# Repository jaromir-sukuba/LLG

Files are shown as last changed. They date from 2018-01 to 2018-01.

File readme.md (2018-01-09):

This is repository for project LLG - ligh level geolocator.
This geolocator uses movement of sun, sensed by single photoresistor, to estimate its own location on earth with accuracy of few dozens of kilometers. It is able to display and log the position for decades - 10 years of running/logging with display on, 30 years of runtime with display off, though only 22 years of logging memeory. Considering the battery has shelf life ~ 10 years, it's not that bad. 



/fw/ - MPLABX project expecting XC16 compiler to build. 

/hw/pcb/ - Eagle design files. Created in Eagle 6.4, 5x5cm, so it fits free version.

/hw/enclosure/ - FreeCad and stl files of enclosure I used



See https://hackaday.io/project/28550-light-level-geolocator for more.

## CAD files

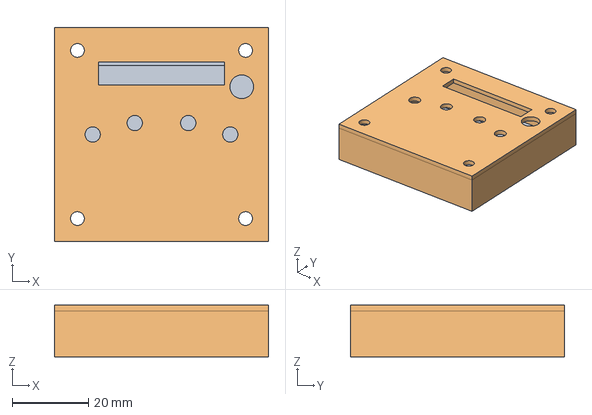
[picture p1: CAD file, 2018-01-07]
hw/enclosure/llg_enclosure.fcstd
56.0 x 56.0 x 13.5 mm

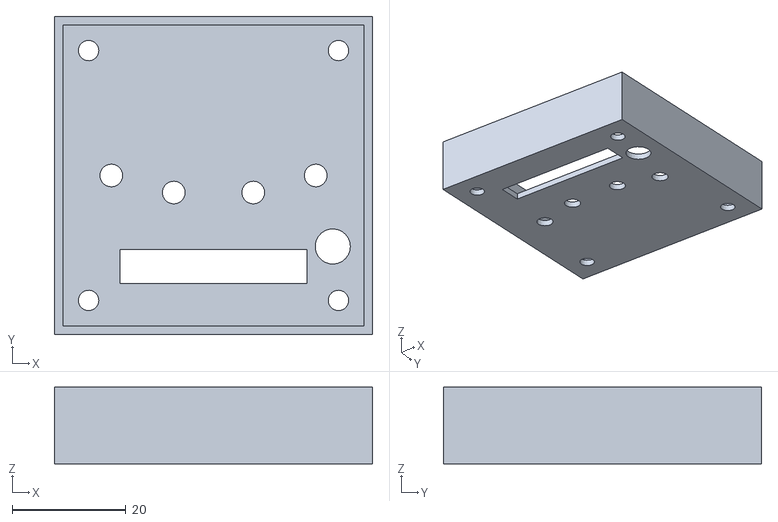
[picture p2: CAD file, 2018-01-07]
hw/enclosure/llg_part1.stl
56.0 x 56.0 x 13.5

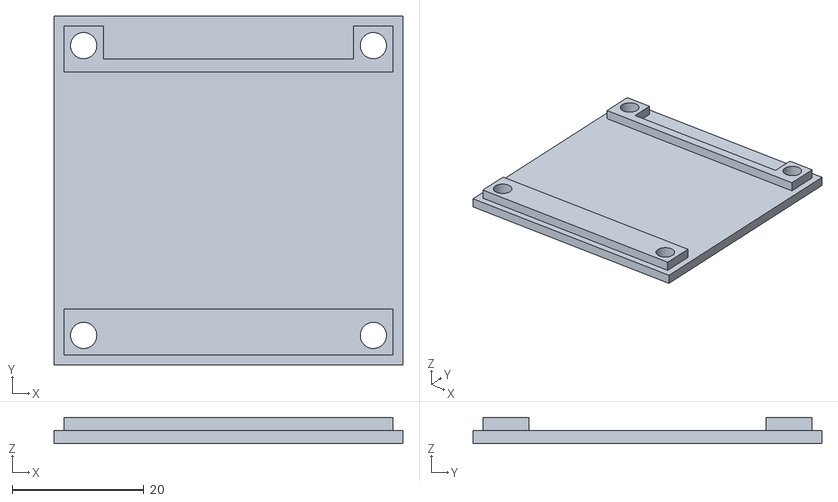
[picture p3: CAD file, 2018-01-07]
hw/enclosure/llg_part2.stl
53.0 x 53.0 x 4.00

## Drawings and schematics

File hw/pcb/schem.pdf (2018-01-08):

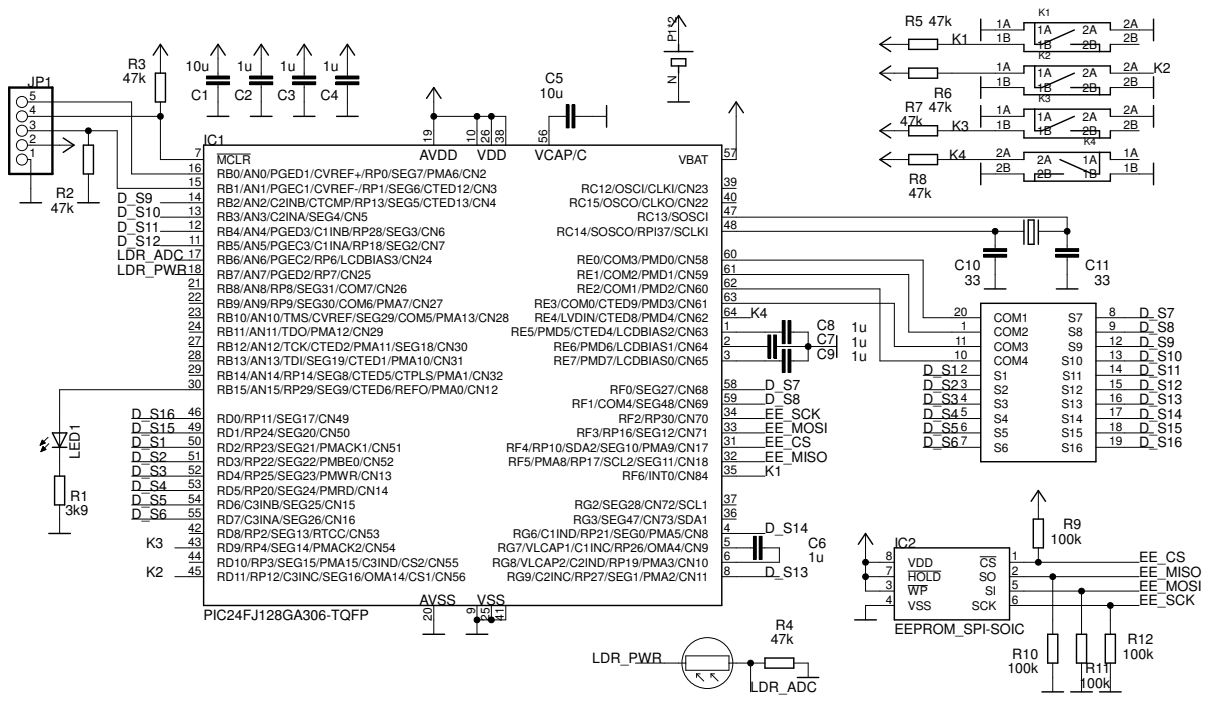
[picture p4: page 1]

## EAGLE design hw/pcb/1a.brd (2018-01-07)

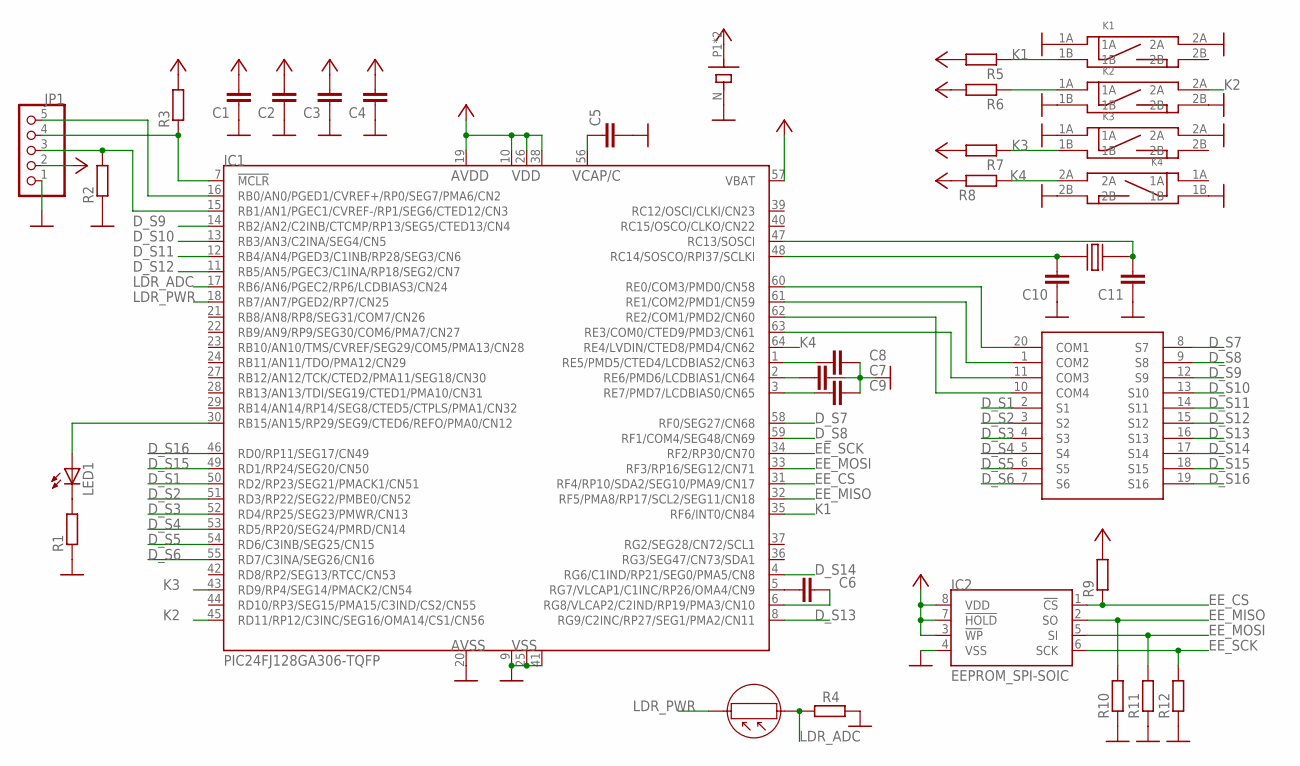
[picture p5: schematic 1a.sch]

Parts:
C1: C_1206; R1206
C2, C3, C4, C5, C6, C7, C8, C9, C10, C11: C_0603; 0603
IC1: PIC24FJ128GA306-TQFP; TQFP64-10X10
IC2: EEPROM_SPI-SOIC; SO-08
JP1: PINHD-1X05_2.00; 1X05M
K1, K2, K3, K4: SWITCH_BD_B; SW_SMD2
LCD1: LCD_DE188
LDR1: LDR; LDR_5
LED1: LEDCHIPLED_0805; CHIPLED_0805
R1, R2, R3, R4, R5, R6, R7, R8, R9, R10, R11, R12: R_0603; 0603
U$1: BATTK3002; BATT_KEYS3002
X1: CRYST_TC26MC146; CRYST_MC146

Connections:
D_S1: IC1.50 (RD2/RP23/SEG21/PMACK1/CN51), LCD1.2 (S1)
D_S2: IC1.51 (RD3/RP22/SEG22/PMBE0/CN52), LCD1.3 (S2)
D_S3: IC1.52 (RD4/RP25/SEG23/PMWR/CN13), LCD1.4 (S3)
D_S4: IC1.53 (RD5/RP20/SEG24/PMRD/CN14), LCD1.5 (S4)
D_S5: IC1.54 (RD6/C3INB/SEG25/CN15), LCD1.6 (S5)
D_S6: IC1.55 (RD7/C3INA/SEG26/CN16), LCD1.7 (S6)
D_S7: IC1.58 (RF0/SEG27/CN68), LCD1.8 (S7)
D_S8: IC1.59 (RF1/COM4/SEG48/CN69), LCD1.9 (S8)
D_S9: IC1.14 (RB2/AN2/C2INB/CTCMP/RP13/SEG5/CTED13/CN4), LCD1.12 (S9)
D_S10: IC1.13 (RB3/AN3/C2INA/SEG4/CN5), LCD1.13 (S10)
D_S11: IC1.12 (RB4/AN4/PGED3/C1INB/RP28/SEG3/CN6), LCD1.14 (S11)
D_S12: IC1.11 (RB5/AN5/PGEC3/C1INA/RP18/SEG2/CN7), LCD1.15 (S12)
D_S13: IC1.8 (RG9/C2INC/RP27/SEG1/PMA2/CN11), LCD1.16 (S13)
D_S14: IC1.4 (RG6/C1IND/RP21/SEG0/PMA5/CN8), LCD1.17 (S14)
D_S15: IC1.49 (RD1/RP24/SEG20/CN50), LCD1.18 (S15)
D_S16: IC1.46 (RD0/RP11/SEG17/CN49), LCD1.19 (S16)
EE_CS: IC1.31 (RF4/RP10/SDA2/SEG10/PMA9/CN17), IC2.1 (!CS), R9.1
EE_MISO: IC1.32 (RF5/PMA8/RP17/SCL2/SEG11/CN18), IC2.2 (SO), R10.2
EE_MOSI: IC1.33 (RF3/RP16/SEG12/CN71), IC2.5 (SI), R11.2
EE_SCK: IC1.34 (RF2/RP30/CN70), IC2.6 (SCK), R12.2
GND: C1.1, C2.1, C3.1, C4.1, C5.2, C7.1, C8.1, C9.1, C10.1, C11.1, IC1.9 (VSS), IC1.20 (AVSS), IC1.25 (VSS), IC1.41 (VSS), IC2.4 (VSS), JP1.1, K1.1A, K1.2A, K2.1B, K2.2B, K3.1A, K3.2A, K4.1B, K4.2B, R1.1, R2.1, R4.1, R10.1, R11.1, R12.1, U$1.N (M)
K1: IC1.35 (RF6/INT0/CN84), K1.1B, R5.1
K2: IC1.45 (RD11/RP12/C3INC/SEG16/OMA14/CS1/CN56), K2.2A
K3: IC1.43 (RD9/RP4/SEG14/PMACK2/CN54), K3.1B, R7.1
K4: IC1.64 (RE4/LVDIN/CTED8/PMD4/CN62), K4.2A, R8.2
LDR_ADC: IC1.17 (RB6/AN6/PGEC2/RP6/LCDBIAS3/CN24), LDR1.P$1, R4.2
LDR_PWR: IC1.18 (RB7/AN7/PGED2/RP7/CN25), LDR1.P$2
unnamed: C5.1, IC1.56 (C)
unnamed: C11.2, IC1.47 (RC13/SOSCI), X1.1
unnamed: C10.2, IC1.48 (RC14/SOSCO/RPI37/SCLKI), X1.4
unnamed: IC1.60 (RE0/COM3/PMD0/CN58), LCD1.20 (COM1)
unnamed: IC1.61 (RE1/COM2/PMD1/CN59), LCD1.1 (COM2)
unnamed: IC1.63 (RE3/COM0/CTED9/PMD3/CN61), LCD1.11 (COM3)
unnamed: IC1.62 (RE2/COM1/PMD2/CN60), LCD1.10 (COM4)
unnamed: C8.2, IC1.1 (RE5/PMD5/CTED4/LCDBIAS2/CN63)
unnamed: C7.2, IC1.2 (RE6/PMD6/LCDBIAS1/CN64)
unnamed: C9.2, IC1.3 (RE7/PMD7/LCDBIAS0/CN65)
unnamed: LED1.C, R1.2
unnamed: IC1.30 (RB15/AN15/RP29/SEG9/CTED6/REFO/PMA0/CN12), LED1.A
unnamed: K2.1A, R6.1
unnamed: C6.2, IC1.5 (RG7/VLCAP1/C1INC/RP26/OMA4/CN9)
unnamed: C6.1, IC1.6 (RG8/VLCAP2/C2IND/RP19/PMA3/CN10)
unnamed: IC1.15 (RB1/AN1/PGEC1/CVREF-/RP1/SEG6/CTED12/CN3), JP1.3, R2.2
unnamed: IC1.16 (RB0/AN0/PGED1/CVREF+/RP0/SEG7/PMA6/CN2), JP1.5
unnamed: IC1.7 (!MCLR), JP1.4, R3.1
VCC: C1.2, C2.2, C3.2, C4.2, IC1.10 (VDD), IC1.19 (AVDD), IC1.26 (VDD), IC1.38 (VDD), IC1.57 (VBAT), IC2.3 (!WP), IC2.7 (!HOLD), IC2.8 (VDD), JP1.2, R3.2, R5.2, R6.2, R7.2, R8.1, R9.2, U$1.P1, U$1.P2

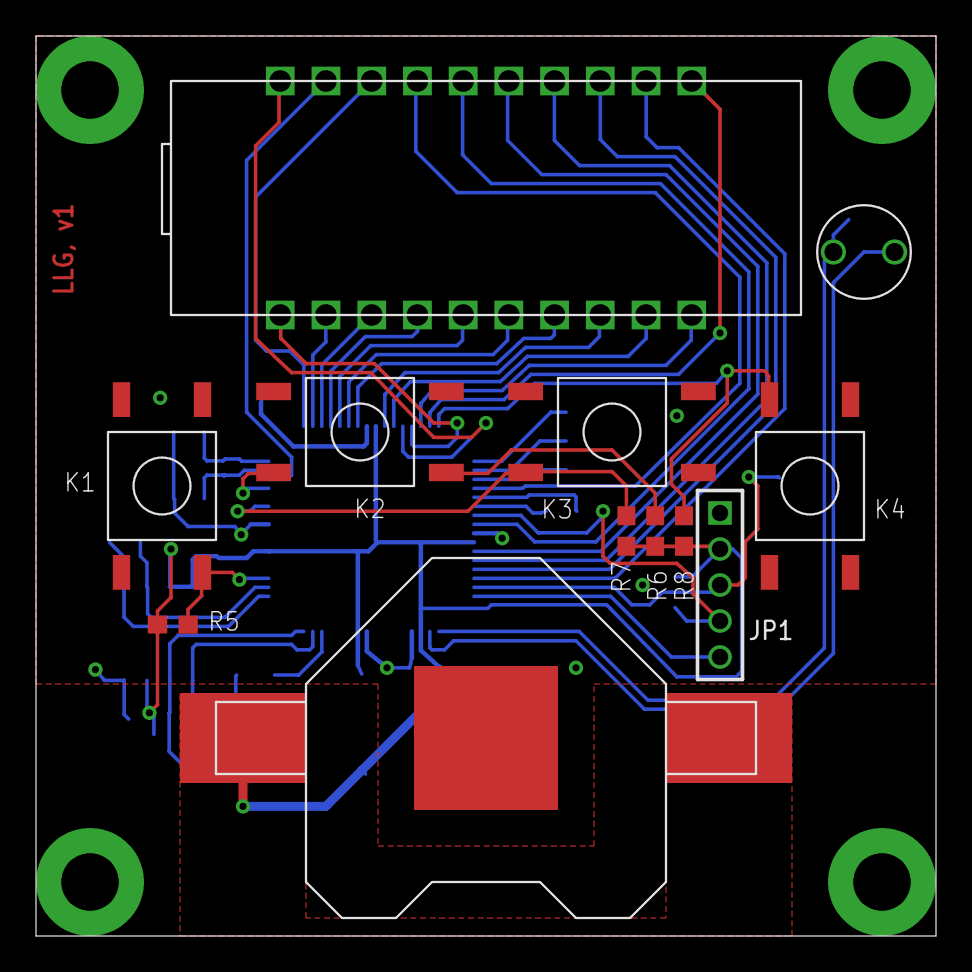
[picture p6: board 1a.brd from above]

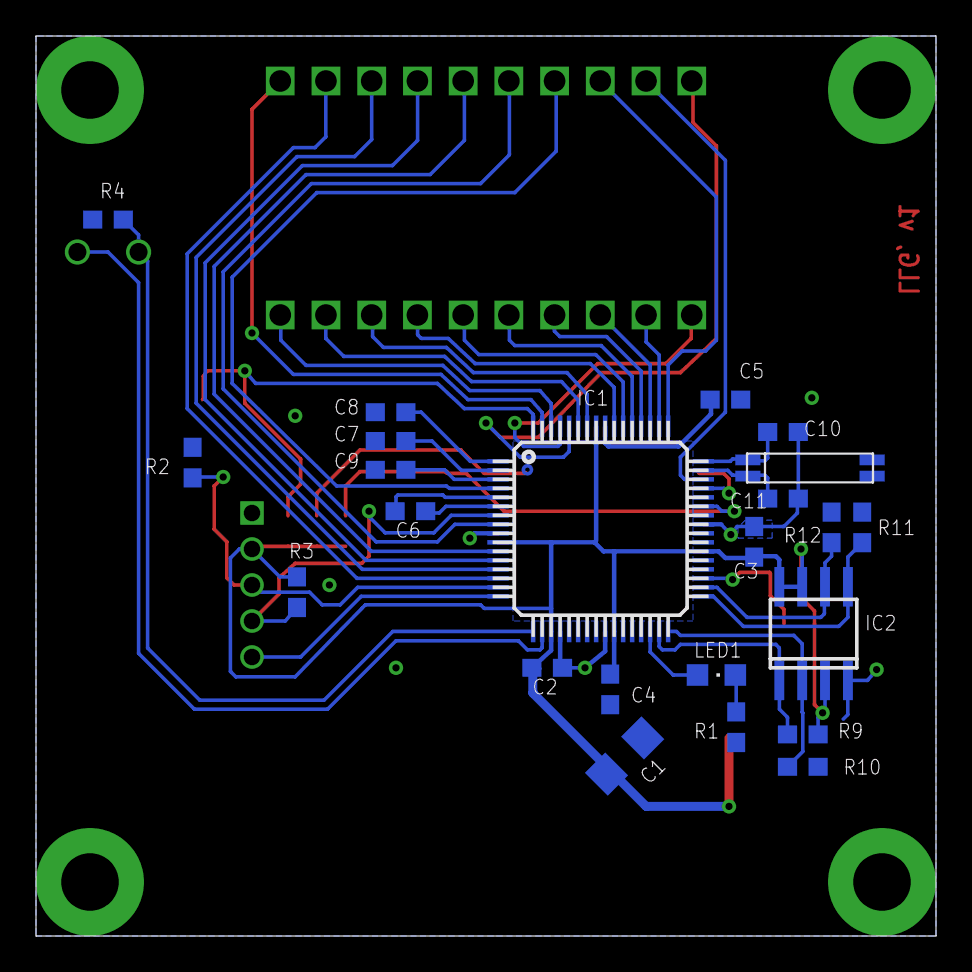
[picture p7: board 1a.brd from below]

Board: 2 copper layers, 50.0 x 50.0 mm, 35 parts (23 on the bottom side), 46 nets.

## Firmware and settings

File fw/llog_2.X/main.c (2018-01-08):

#include <xc.h>
#include <stdio.h>
#include "lcd.h"
#include "geo.h"
#include "hw.h"


//init test data, 2.1.2018
const uint16_t ll_vals[1440] = {
4, 4, 4, 4, 4, 4, 4, 4, 4, 4, 4, 4, 4, 4, 4, 4, 4, 4, 4, 4, 4, 4, 4, 4, 4, 4, 4, 4, 4, 4, 4, 4, 4, 4, 4, 4, 4, 4, 4, 4, 4, 4, 4, 4, 4, 4, 4, 
4, 4, 4, 4, 4, 4, 4, 4, 4, 4, 4, 4, 4, 4, 4, 4, 4, 4, 4, 4, 4, 4, 4, 4, 4, 4, 4, 4, 4, 4, 4, 4, 4, 4, 4, 4, 4, 4, 4, 4, 4, 4, 4, 4, 4, 4, 4, 
4, 4, 4, 4, 4, 4, 4, 4, 4, 4, 4, 4, 4, 4, 4, 4, 4, 4, 4, 4, 4, 4, 4, 4, 4, 4, 4, 4, 4, 4, 4, 4, 4, 4, 4, 4, 4, 4, 4, 4, 4, 4, 4, 4, 4, 4, 4, 
4, 4, 4, 4, 4, 4, 4, 4, 4, 4, 4, 4, 4, 4, 3, 4, 4, 4, 4, 4, 3, 3, 3, 3, 4, 4, 4, 4, 4, 4, 4, 4, 4, 4, 4, 4, 4, 4, 3, 3, 3, 3, 3, 3, 3, 3, 3, 
3, 3, 3, 3, 3, 3, 3, 3, 3, 3, 3, 3, 3, 3, 3, 3, 3, 3, 3, 3, 3, 3, 3, 3, 3, 3, 3, 3, 3, 3, 3, 3, 3, 3, 3, 3, 3, 3, 3, 3, 3, 3, 3,
 3, 3, 3, 3, 3, 3, 3, 3, 3, 3, 3, 3, 3, 3, 3, 3, 3, 3, 3, 3, 3, 3, 3, 3, 3, 3, 3, 3, 3, 3, 3, 3, 3, 3, 3, 3, 3, 2, 2, 2, 3, 2, 3, 3, 3, 3, 
3, 3, 3, 2, 2, 2, 2, 2, 2, 2, 3, 3, 3, 3, 3, 3, 3, 4, 4, 4, 5, 5, 6, 7, 8, 9, 10, 12, 13, 15, 18, 20, 23, 26, 30, 34, 39, 45, 52, 59, 66, 
74, 82, 91, 100, 108, 116, 124, 132, 139, 146, 153, 160, 166, 172, 178, 184, 190, 194, 198, 201, 204, 207, 209, 211, 213, 215, 217, 218, 
220, 220, 221, 221, 222, 223, 223, 223, 223, 223, 224, 224, 225, 225, 225, 224, 223, 221, 220, 218, 218, 218, 218, 219, 220, 221, 222, 224, 
225, 227, 228, 229, 231, 232, 233, 234, 235, 236, 237, 239, 239, 240, 241, 241, 242, 242, 242, 242, 243, 243, 244, 244, 244, 244, 244, 244,
 244, 244, 244, 245, 245, 245, 245, 245, 245, 245, 245, 245, 246, 246, 246, 246, 245, 245, 245, 246, 246, 246, 246, 246, 247, 247, 247, 247, 
247, 247, 247, 247, 247, 247, 248, 248, 248, 248, 248, 248, 248, 248, 249, 249, 249, 249, 249, 249, 249, 249, 248, 248, 248, 248, 248, 248, 
247, 247, 248, 248, 248, 248, 248, 248, 248, 248, 248, 248, 248, 247, 247, 247, 248, 248, 248, 248, 248, 248, 248, 248, 248, 248, 248, 248, 
247, 247, 247, 246, 244, 243, 243, 244, 244, 244, 245, 245, 244, 244, 244, 245, 246, 247, 247, 248, 248, 248, 248, 248, 248, 249, 249, 249, 
249, 249, 250, 250, 250, 249, 249, 248, 249, 249, 249, 248, 248, 248, 248, 248, 248, 248, 248, 247, 246, 246, 246, 246, 246, 244, 243, 243, 
244, 245, 246, 245, 245, 245, 245, 245, 244, 244, 244, 243, 242, 240, 236, 232, 229, 226, 224, 223, 223, 223, 224, 224, 223, 224, 225, 225, 
225, 226, 228, 232, 234, 235, 237, 239, 241, 244, 245, 246, 246, 246, 246, 246, 246, 246,
 246, 246, 247, 247, 247, 247, 247, 247, 246, 246, 247, 247, 248, 248, 249, 250, 250, 249, 249, 249, 249, 249, 250, 250, 249, 249, 249, 248, 
248, 248, 247, 247, 246, 245, 245, 245, 245, 246, 246, 246, 246, 245, 244, 245, 245, 245, 246, 246, 247, 248, 248, 248, 248, 249, 249, 249, 
249, 249, 248, 248, 247, 247, 247, 247, 248, 247, 247, 247, 247, 246, 247, 246, 246, 247, 246, 246, 245, 245, 245, 245, 245, 245, 244, 244, 
244, 244, 244, 244, 243, 244, 244, 244, 243, 243, 242, 241, 241, 241, 240, 239, 239, 237, 236, 237, 237, 237, 237, 237, 237, 237, 237, 237, 
236, 236, 236, 235, 235, 235, 234, 234, 233, 233, 232, 231, 231, 230, 230, 230, 229, 228, 228, 230, 
230, 231, 232, 231, 232, 231, 233, 234, 235, 234, 233, 233, 233, 233, 232, 232, 231, 231, 232, 232, 232, 231, 232, 232, 234, 234, 234, 235, 
236, 237, 236, 236, 235, 233, 231, 230, 229, 228, 227, 227, 227, 227, 227, 227, 227, 226, 226, 226, 227, 227, 226, 226, 226, 227, 228, 227, 
226, 225, 225, 225, 227, 229, 231, 231, 232, 232, 232, 232, 232, 231, 231, 230, 230, 229, 229, 228, 228, 228, 227, 227, 226, 225, 224, 223, 
222, 221, 219, 217, 216, 214, 213, 211, 
210, 210, 210, 209, 208, 206, 204, 202, 199, 196, 194, 191, 189, 188, 187, 186, 187, 188, 189, 190, 191, 190, 189, 188, 185, 183, 181, 179, 
178, 176, 174, 172, 171, 168, 166, 163, 160, 157, 156, 154, 151, 149, 145, 139, 131, 120, 108, 96, 85, 76, 71, 68, 65, 61, 57, 54, 51, 47, 
42, 37, 32, 28, 26, 23, 20, 17, 14, 12, 10, 9, 8, 7, 6, 5, 5, 4, 4, 4, 3, 3, 3, 3, 3, 3, 3, 2, 2, 2, 2, 2, 2, 2, 2, 2, 2, 2, 2, 2, 2, 2, 2, 
2, 2, 2, 2, 2, 2, 2, 2, 2, 2, 2, 2, 2, 2, 2, 2, 2, 2, 2, 2, 2, 2, 3, 3, 3, 3, 3, 3, 3, 3, 3, 3, 3, 3, 3, 2, 3, 3, 3, 3, 3, 3, 3, 3, 3, 3, 3, 
3, 3, 3, 3, 3, 3, 3, 3, 3, 2, 2, 3, 3, 2, 2, 2, 2, 2, 2, 2, 3, 2, 2, 3, 3, 3, 2, 3, 3, 3, 3, 3, 3, 2, 2, 2, 2, 2, 2, 2, 2, 2, 3, 3, 3, 2, 2, 
2, 3, 3, 2, 2, 3, 3, 3, 3, 3, 3, 3, 3, 3, 2, 2, 2, 2, 3, 3, 3, 3, 3, 3, 2, 2, 2, 2, 2, 2, 2, 2, 2, 2, 2, 2, 2, 2, 2, 2, 2, 2, 2, 2, 3, 3, 3, 
2, 3, 3, 3, 3, 2, 2, 2, 2, 3, 3, 3, 3, 3, 3, 3, 3, 3, 3, 3, 3, 3, 3, 3, 2, 2, 2, 2, 2, 
2, 2, 3, 2, 2, 3, 3, 3, 2, 3, 3, 3, 3, 3, 2, 3, 2, 2, 2, 2, 3, 2, 2, 2, 2, 2, 3, 3, 3, 3, 3, 3, 3, 3, 3, 3, 3, 3, 3, 3, 3, 3, 3, 3, 3, 3, 3, 
3, 3, 3, 3, 3, 3, 3, 3, 3, 3, 3, 2, 3, 3, 3, 3, 3, 3, 3, 3, 2, 2, 2, 2, 2, 2, 3, 2, 3, 3, 3, 2, 2, 2, 2, 2, 2, 2, 2, 3, 2, 2, 2, 2, 2, 2, 2, 
3, 2, 2, 2, 2, 2, 2, 2, 2, 2, 2, 2, 2, 2, 2, 2, 2, 2, 2, 2, 2, 2, 2, 2, 2, 2, 2, 2, 2, 2, 2, 2, 2, 2, 2, 2, 2, 2, 2, 3, 2, 2, 6, 6, 6, 6, 6, 
2, 2, 2, 2, 2, 2, 2, 2, 2, 2, 2, 2, 2, 2, 2, 2, 2, 2, 2, 2, 2, 2, 2, 2, 2, 2, 2, 2, 2, 2, 2, 2, 2, 2, 2, 2, 2, 2, 2, 2, 2, 2, 2, 2, 2, 2, 2, 
2, 2, 2, 2, 2, 2, 2, 2, 3, 2, 2, 2, 3, 2, 2, 2, 2, 2, 3, 3, 3, 3, 2, 2, 3, 3, 3, 3, 3, 2, 3, 3, 3, 3, 3, 3, 3, 3, 3, 3, 88, 3, 3, 
4, 3, 3, 3, 3, 3, 3, 4, 4, 3, 3, 3, 3, 3, 3, 3, 3, 4, 3, 3, 4, 4, 3, 3, 3, 3, 3, 3, 3, 3, 4, 4, 4, 4, 3, 4, 4, 4, 4, 4, 4, 4, 4, 4, 4, 4, 4, 
4, 4, 4, 4, 4, 4, 3, 3, 3, 4, 3, 3, 3, 3, 4, 3, 3, 3, 3, 3, 3, 4, 3, 3, 3, 4, 4, 4, 3, 3, 3, 3, 3, 4, 3, 3, 3, 3, 3, 3, 4, 3, 4, 3, 3, 3, 4, 
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

	
};

void display_time (char * line, char * msg, uint8_t v1, uint8_t v2, uint8_t v3, uint8_t v4, uint8_t blank);
void display_date (char * line, char * msg, uint8_t v1, uint8_t v2, uint8_t v3, uint8_t v4, uint8_t blank);
void refresh_lcd_arrays (void);

#define		IDLE_CNT_MAX	10

rtc_t rtc_now,rtc_set;
key_t keys,keys_new,keys_old;
uint8_t main_state,edit_ptr,edit_blank,edit_blank_tmr,main_state_prev,day,month,lcd_state;
uint16_t ll_log_arr[LL_LOG_SIZE],ll_log_ptr=0,mem_log_ptr=0,ee_read_addr=0;
uint16_t i,t,idle_cnt;
char lcd_array[10], lcd_array_o[10],lcd_array_lat[10],lcd_array_lon[10],lcd_array_log[10],tx_str[25];
uint16_t val;
double day_length,solar_noon,declination,latitude,longitude,eq_of_time,lat_read,lon_read;

uint8_t ee_array[8];


void _ISR __attribute__((auto_psv)) _RTCCInterrupt(void)
{
IFS3bits.RTCIF = 0;
ALCFGRPTbits.ALRMEN = 1;
main_state_prev = main_state;
main_state = MS_UPDATE;
}

void _ISR __attribute__((auto_psv)) _T1Interrupt(void)
{
IFS0bits.T1IF = 0;
}

void _ISR __attribute__((auto_psv)) _INT0Interrupt(void)
{
IFS0bits.INT0IF = 0;
main_state = MS_DISP_TIME;
idle_cnt = IDLE_CNT_MAX;
}



int main(void)
	{
	clock_frc();
	main_init();
	refresh_lcd_arrays();
	idle_cnt = IDLE_CNT_MAX;
	for (i=0;i<LL_LOG_SIZE;i++)
		ll_log_arr[i] = ll_vals[i]*4;
	analyze_ll_data(ll_log_arr,LL_LOG_SIZE,&day_length,&solar_noon);
	solar_noon = solar_noon + 1.0;
	declination = get_declination(3,1);
	eq_of_time = get_eq_time(3,1);
	latitude = get_latitude(day_length,-3.0,declination);
	longitude = get_longitude(solar_noon,eq_of_time);
	mem_log_ptr++;
	refresh_lcd_arrays();
	clock_lprc();
	lcd_state = 1;
	while (1)
		{
		if (timer_elapsed())
			{
			keys_new.CHAR = keys_state();
			keys.CHAR = keys.CHAR | ((keys_new.CHAR^keys_old.CHAR)&keys_new.CHAR);
			keys_old.CHAR = keys_new.CHAR;
			if (keys_new.CHAR!=0) idle_cnt = IDLE_CNT_MAX;
			rtc_read(&rtc_now);
			edit_blank_tmr++;
			if (edit_blank_tmr==10)
				{
				edit_blank_tmr=0;
				if (edit_blank==0) edit_blank = 10;
				else edit_blank=0;
				
				if (idle_cnt!=0)
					idle_cnt--;
				else
					main_state = MS_IDLE;
				}
			}
		if (main_state==MS_IDLE)
			{
			rtc_read(&rtc_now);
			display_time(lcd_array,"  ",rtc_now.hrs_t,rtc_now.hrs_o,rtc_now.min_t,rtc_now.min_o,10);
			lcd_write_chars(lcd_array,LCD_P1|LCD_X);
			shdn(lcd_state);
			}
		if (main_state==MS_CALCULATE)
			{
			if (ll_log_ptr>(LL_LOG_SIZE-5))
				{
				clock_frc();
				day = rtc_now.day_t*10 + rtc_now.day_o*1;
				month = rtc_now.mon_t*10 + rtc_now.mon_o*1;
				lcd_write_chars("calculate",0);
				analyze_ll_data(ll_log_arr,LL_LOG_SIZE,&day_length,&solar_noon);
				solar_noon = solar_noon + 0.0;
				declination = get_declination(day,month);
				eq_of_time = get_eq_time(day,month);
				latitude = get_latitude(day_length,-3.0,declination);
				longitude = get_longitude(solar_noon,eq_of_time);
				if (mem_log_ptr<MAX_EE_LOG_PTR)
					{
					prepare_mem_log(latitude,longitude,ee_array);
					ee_write_page(mem_log_ptr*EE_PAGE_SIZE,ee_array,EE_PAGE_SIZE*2);//writing 8 bytes, last 4 are only 0xFF to denote end of record
					mem_log_ptr++;										//those 4 bytes will be overwritten on next record
					}
				refresh_lcd_arrays();
				clock_lprc();
				}
			ll_log_ptr = 0;
			main_state = main_state_prev;
			}
		if (main_state==MS_UPDATE)
			{
			clock_frc();
			LDR_PWR = 1;
			main_state = main_state_prev;
			rtc_read(&rtc_now);
			//ll_log_arr[ll_log_ptr] = ll_vals[ll_log_ptr];
			ll_log_arr[ll_log_ptr] = get_adc(LDR_ADC_CHNL) / 4;
			ll_log_ptr++;
			LDR_PWR = 0;
			if ((rtc_now.min_o==0)&(rtc_now.min_t==0)&(rtc_now.hrs_o==0)&(rtc_now.hrs_t==0))
			//if (ll_log_ptr==LL_LOG_SIZE)
				{
				main_state = MS_CALCULATE;
				}
			clock_lprc();
			}
		
		if (main_state==MS_DISP_TIME)
			{
			//display_time(lcd_array,"te",rtc_now.min_t,rtc_now.min_o,rtc_now.sec_t,rtc_now.sec_o,10);
			display_time(lcd_array,"tn",rtc_now.hrs_t,rtc_now.hrs_o,rtc_now.min_t,rtc_now.min_o,10);
			lcd_write_chars(lcd_array,LCD_P1);
			if (keys.k1)
				{
				keys.k1 = 0;
				main_state = MS_DISP_DATE;
				}
			if (keys.k2)
				{
				keys.k2 = 0;
				main_state = MS_EDIT_TIME;
				rtc_read(&rtc_set);
				}
			}
		if (main_state==MS_DISP_DATE)
			{
			display_date(lcd_array,"dn",rtc_now.mon_t,rtc_now.mon_o,rtc_now.day_t,rtc_now.day_o,10);
			lcd_write_chars(lcd_array,0);
			if (keys.k1)
				{
				keys.k1 = 0;
				main_state = MS_DISP_LAT;
				}
			if (keys.k2)
				{
				keys.k2 = 0;
				main_state = MS_EDIT_DATE;
				rtc_read(&rtc_set);
				}
			}
		if (main_state==MS_DISP_LAT)
			{
			lcd_write_chars(lcd_array_lat,0);
			if (keys.k1)
				{
				keys.k1 = 0;
				main_state = MS_DISP_LON;
				}
			}
		if (main_state==MS_DISP_LON)
			{
			lcd_write_chars(lcd_array_lon,0);
			if (keys.k1)
				{
				keys.k1 = 0;
				main_state = MS_DISP_LOG;
				}
			}
		if (main_state==MS_DISP_LOG)
			{
			lcd_write_chars(lcd_array_log,0);
			if (keys.k1)
				{
				keys.k1 = 0;
				main_state = MS_DISP_SND;
				}
			}		
		if (main_state==MS_DISP_SND)
			{
			lcd_write_chars("send log",0);
			if (keys.k1)
				{
				keys.k1 = 0;
				main_state = MS_LCDST;
				}
			if (keys.k2)
				{
				keys.k2 = 0;
				main_state = MS_DISP_SENDING;
				ee_read_addr = 0;
				clock_frc();
				}
			}
		if (main_state==MS_DISP_SENDING)
			{
			idle_cnt = IDLE_CNT_MAX;
			if (edit_blank==0)
				lcd_write_chars("WAIT_   ",0);
			else
				lcd_write_chars("WAIT-   ",0);
			ee_read_page(ee_read_addr*4,ee_array,4);
			if (ee_array[0]==0xFF)
				{
				main_state = MS_DISP_SND;
				clock_lprc();
				}
			else
				{
				read_mem_log(&lat_read,&lon_read,ee_array);
				sprintf(tx_str,"%d;%2.2f;%2.2f\n",ee_read_addr,lat_read,lon_read);
				usart_send_str(tx_str);
				ee_read_addr++;
				}
			if (keys.k4)
				{
				keys.k4 = 0;
				main_state = MS_DISP_SND;
				clock_lprc();
				}
			}
		if (main_state==MS_LCDST)
			{
			if (lcd_state==0)
				lcd_write_chars("lcd off ",0);
			else
				lcd_write_chars("lcd on  ",0);
			if (keys.k1)
				{
				keys.k1 = 0;
				main_state = MS_DISP_TIME;
				}
			if (keys.k2)
				{
				keys.k2 = 0;
				if (lcd_state==0)
					lcd_state = 1;
				else
					lcd_state = 0;
				}
			}

		if (main_state==MS_EDIT_TIME)
			{
			display_time(lcd_array,"te",rtc_set.hrs_t,rtc_set.hrs_o,rtc_set.min_t,rtc_set.min_o,edit_ptr+edit_blank);
			lcd_write_chars(lcd_array,0);
			if (keys.k1)
				{
				keys.k1 = 0;
				main_state = MS_DISP_TIME;
				}
			if (keys.k2)
				{
				keys.k2 = 0;
				edit_ptr++;
				if (edit_ptr==4) edit_ptr = 0;
				}
			if (keys.k3)
				{
				keys.k3 = 0;
				if (edit_ptr==0) {rtc_set.hrs_t++; if (rtc_set.hrs_t>2) rtc_set.hrs_t=0;}
				if (edit_ptr==1) {rtc_set.hrs_o++; if (rtc_set.hrs_o>9) rtc_set.hrs_o=0;}
				if (edit_ptr==2) {rtc_set.min_t++; if (rtc_set.min_t>5) rtc_set.min_t=0;}
				if (edit_ptr==3) {rtc_set.min_o++; if (rtc_set.min_o>9) rtc_set.min_o=0;}
				}
			if (keys.k4)
				{
				keys.k4 = 0;
				rtc_write_hm(&rtc_set);
				main_state = MS_DISP_TIME;
				}
			}
		if (main_state==MS_EDIT_DATE)
			{
			display_date(lcd_array,"de",rtc_set.mon_t,rtc_set.mon_o,rtc_set.day_t,rtc_set.day_o,edit_ptr+edit_blank);
			lcd_write_chars(lcd_array,0);
			if (keys.k1)
				{
				keys.k1 = 0;
				main_state = MS_DISP_DATE;
				}
			if (keys.k2)
				{
				keys.k2 = 0;
				edit_ptr++;
				if (edit_ptr==4) edit_ptr = 0;
				}
			if (keys.k3)
				{
				keys.k3 = 0;
				if (edit_ptr==0) {rtc_set.mon_t++; if (rtc_set.mon_t>1) rtc_set.mon_t=0;}
				if (edit_ptr==1) {rtc_set.mon_o++; if (rtc_set.mon_o>9) rtc_set.mon_o=0;}
				if (edit_ptr==2) {rtc_set.day_t++; if (rtc_set.day_t>3) rtc_set.day_t=0;}
				if (edit_ptr==3) {rtc_set.day_o++; if (rtc_set.day_o>9) rtc_set.day_o=0;}
				}
			if (keys.k4)
				{
				keys.k4 = 0;
				rtc_write_md(&rtc_set);
				main_state = MS_DISP_DATE;
				}
			}
		}
	}


void refresh_lcd_arrays (void)
	{
	sprintf(lcd_array_lat,"LA %1.1f",latitude);
	sprintf(lcd_array_lon,"LO %1.1f",longitude);
	sprintf(lcd_array_log,"LOG %4.4d",mem_log_ptr);
	}


void display_time (char * line, char * msg, uint8_t v1, uint8_t v2, uint8_t v3, uint8_t v4, uint8_t blank)
	{
	line[0] = msg[0];
	line[1] = msg[1];
	line[2]	= ' ';
	line[3]	= ' ';
	line[4]	= '0'+v1;
	line[5]	= '0'+v2;
	line[6]	= '0'+v3;
	line[7]	= '0'+v4;
	if (blank==0) line[4] = ' ';
	if (blank==1) line[5] = ' ';
	if (blank==2) line[6] = ' ';
	if (blank==3) line[7] = ' ';
	}

void display_date (char * line, char * msg, uint8_t v1, uint8_t v2, uint8_t v3, uint8_t v4, uint8_t blank)
	{
	line[0] = msg[0];
	line[1] = msg[1];
	line[2]	= ' ';
	line[3]	= '0'+v1;
	line[4]	= '0'+v2;
	line[5]	= '-';
	line[6]	= '0'+v3;
	line[7]	= '0'+v4;
	if (blank==0) line[3] = ' ';
	if (blank==1) line[4] = ' ';
	if (blank==2) line[6] = ' ';
	if (blank==3) line[7] = ' ';

	}


	/*
	for (i=0;i<LL_LOG_SIZE;i++)
		ll_log_arr[i] = ll_vals[i]*4;
	analyze_ll_data(ll_log_arr,LL_LOG_SIZE,&day_length,&solar_noon);
	solar_noon = solar_noon + 1.0;
	declination = get_declination(3,1);
	eq_of_time = get_eq_time(3,1);
	latitude = get_latitude(day_length,-3.0,declination);
	longitude = get_longitude(solar_noon,eq_of_time);

	lcd_write_chars("12345678",LCD_P1|LCD_P2|LCD_X);
		 * 	 */

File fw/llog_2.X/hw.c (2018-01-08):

#include <xc.h>
#include "lcd.h"
#include "hw.h"

//#define		DEBUG_CLOCK		1


// CONFIG4
#pragma config DSWDTPS = DSWDTPS1F      // Deep Sleep Watchdog Timer Postscale Select bits (1:68719476736 (25.7 Days))
#pragma config DSWDTOSC = LPRC          // DSWDT Reference Clock Select (DSWDT uses LPRC as reference clock)
#pragma config DSBOREN = OFF            // Deep Sleep BOR Enable bit (DSBOR Disabled)
#pragma config DSWDTEN = OFF            // Deep Sleep Watchdog Timer Enable (DSWDT Disabled)
#pragma config DSSWEN = ON              // DSEN Bit Enable (Deep Sleep is controlled by the register bit DSEN)

// CONFIG3
#pragma config WPFP = WPFP127           // Write Protection Flash Page Segment Boundary (Page 127 (0x1FC00))
#pragma config VBTBOR = OFF             // VBAT BOR enable bit (VBAT BOR disabled)
#pragma config SOSCSEL = ON             // SOSC Selection bits (SOSC circuit selected)
#pragma config WDTWIN = PS25_0          // Watch Dog Timer Window Width (Watch Dog Timer Window Width is 25 percent)
#pragma config BOREN = OFF              // Brown-out Reset Enable (Brown-out Reset Disabled)
#pragma config WPDIS = WPDIS            // Segment Write Protection Disable (Disabled)
#pragma config WPCFG = WPCFGDIS         // Write Protect Configuration Page Select (Disabled)
#pragma config WPEND = WPENDMEM         // Segment Write Protection End Page Select (Write Protect from WPFP to the last page of memory)

// CONFIG2
#pragma config POSCMD = NONE            // Primary Oscillator Select (Primary Oscillator Disabled)
#pragma config BOREN1 = DIS             // BOR Override bit (BOR Disabled [When BOREN=0])
#pragma config IOL1WAY = OFF            // IOLOCK One-Way Set Enable bit (The IOLOCK bit can be set and cleared using the unlock sequence)
#pragma config OSCIOFCN = ON            // OSCO Pin Configuration (OSCO/CLKO/RC15 functions as port I/O (RC15))
#pragma config FCKSM = CSECMD           // Clock Switching and Fail-Safe Clock Monitor Configuration bits (Clock switching is enabled, Fail-Safe Clock Monitor is disabled)
#pragma config FNOSC = FRCDIV           // Initial Oscillator Select (Fast RC Oscillator with Postscaler (FRCDIV))
#pragma config ALTVREF = DLT_AV_DLT_CV  // Alternate VREF/CVREF Pins Selection bit (Voltage reference input, ADC =RA9/RA10 Comparator =RA9,RA10)
#pragma config IESO = ON                // Internal External Switchover (Enabled)

// CONFIG1
#pragma config WDTPS = PS32768          // Watchdog Timer Postscaler Select (1:32,768)
#pragma config FWPSA = PR128            // WDT Prescaler Ratio Select (1:128)
#pragma config FWDTEN = WDT_DIS         // Watchdog Timer Enable (WDT disabled in hardware; SWDTEN bit disabled)
#pragma config WINDIS = OFF             // Windowed WDT Disable (Standard Watchdog Timer)
#pragma config ICS = PGx1               // Emulator Pin Placement Select bits (Emulator functions are shared with PGEC1/PGED1)
#pragma config LPCFG = ON               // Low power regulator control (Enabled)
#pragma config GWRP = OFF               // General Segment Write Protect (Disabled)
#pragma config GCP = OFF                // General Segment Code Protect (Code protection is disabled)
#pragma config JTAGEN = OFF             // JTAG Port Enable (Disabled)

/*
 
 * 8M - 1100uA	-	0
 * 4M - 1050uA	-	1
 * 2M - 650uA	-	2
 * 1M - 380uA	-	3
 * 500k - 365uA	-	4
 * 250k - 300uA	-	5
 * 125k - 288uA	-	6
 * 31k - 280uA	-	7
 * 
 * 31k LPRC - 22uA
 */

void main_init (void)
	{
	CLKDIVbits.RCDIV = 3;	//1MHz

	PMD1 = 0xFFFF;
	PMD2 = 0xFFFF;
	PMD3 = 0xFDFF;
	PMD4 = 0xFFFF;
	PMD6 = 0xFFBF;
	PMD7 = 0xFFFF;

	TRISB = 0x0040;
	TRISC = 0x0000;
	TRISD = 0x0000;
	TRISE = 0x0000;
	TRISF = 0x0000;
	TRISG = 0x0000;
	MEM_CS = 1;
	TRISDbits.TRISD9 = 1;
	TRISDbits.TRISD11 = 1; 
	TRISEbits.TRISE4 = 1;
	TRISFbits.TRISF6 = 1;
	TRISFbits.TRISF5 = 1;
	ANSDbits.ANSD11 = 0;
	ANSEbits.ANSE4 = 0;	

	power_on();	
	enable_lcd();
	
	__builtin_write_RTCWEN();
	ALCFGRPTbits.AMASK = 0b0011;
	ALCFGRPTbits.ALRMEN = 1;
	RTCPWCbits.RTCLK = 0b00;
	RCFGCALbits.RTCWREN = 1;
	RCFGCALbits.RTCEN = 1;
	IEC3bits.RTCIE = 1;
	RCFGCALbits.RTCWREN = 0;
	
//	IEC0bits.INT0IE = 1;
	
	}



void enable_lcd (void)
	{
	LCDCONbits.LMUX = 0b011;
	LCDCONbits.CS = 0b01;
	LCDREFbits.LCDIRE = 1;
	LCDREFbits.LRLAP = 0x01;
	LCDREFbits.LRLBP = 0x01;
	LCDPSbits.LP = 7;
	LCDSE0bits.SE00 = 1;
	LCDSE0bits.SE01 = 1;
	LCDSE0bits.SE02 = 1;
	LCDSE0bits.SE03 = 1;
	LCDSE0bits.SE04 = 1;
	LCDSE0bits.SE05 = 1;
	LCDSE1bits.SE17 = 1;
	LCDSE1bits.SE20 = 1;
	LCDSE1bits.SE21 = 1;
	LCDSE1bits.SE22 = 1;
	LCDSE1bits.SE23 = 1;
	LCDSE1bits.SE24 = 1;
	LCDSE1bits.SE25 = 1;
	LCDSE1bits.SE26 = 1;
	LCDSE1bits.SE27 = 1;
	LCDSE3bits.SE48 = 1;
	LCDCONbits.LCDEN = 1;
	set_segs(0x0000);
	}


void clock_lprc (void)
	{
#ifndef DEBUG_CLOCK
	if (OSCCONbits.COSC!=0b101)
		{
		__builtin_write_OSCCONH(0b101);
		__builtin_write_OSCCONL(0b001);
		}
#endif
	}

void clock_frc (void)
	{
	if (OSCCONbits.COSC!=0b111)
		{
		__builtin_write_OSCCONH(0b111);
		__builtin_write_OSCCONL(0b001);
		}
	}


void rtc_read (rtc_t * rtc_val)
	{
	uint16_t tmp;
	RCFGCALbits.RTCPTR = 0;
	tmp = RTCVAL;
	rtc_val->sec_o = tmp&0xF;
	rtc_val->sec_t = (tmp>>4)&0x7;
	rtc_val->min_o = (tmp>>8)&0xF;
	rtc_val->min_t = (tmp>>12)&0x7;
	RCFGCALbits.RTCPTR = 1;
	tmp = RTCVAL;
	rtc_val->hrs_o = tmp&0xF;
	rtc_val->hrs_t = (tmp>>4)&0x7;
	RCFGCALbits.RTCPTR = 2;
	tmp = RTCVAL;
	rtc_val->day_o = tmp&0xF;
	rtc_val->day_t = (tmp>>4)&0x7;
	rtc_val->mon_o = (tmp>>8)&0xF;
	rtc_val->mon_t = (tmp>>12)&0x7;
	}

void rtc_write_hm (rtc_t * rtc_val)
	{
	uint16_t tmp,tmp2;
	tmp = rtc_val->sec_o;
	tmp = tmp | ((rtc_val->sec_t&0x07)<<4);
	tmp = tmp | ((rtc_val->min_o&0x0F)<<8);
	tmp = tmp | ((rtc_val->min_t&0x07)<<12);
	tmp2 = rtc_val->hrs_o;
	tmp2 = tmp2 | ((rtc_val->hrs_t&0x07)<<4);
	__builtin_write_RTCWEN();
	RCFGCALbits.RTCWREN = 1;
	RCFGCALbits.RTCPTR = 0;
	RTCVAL = tmp;
	RCFGCALbits.RTCPTR = 1;
	RTCVAL = tmp2;
	RCFGCALbits.RTCWREN = 0;
	}

void rtc_write_md (rtc_t * rtc_val)
	{
	unsigned int tmp;
	tmp = rtc_val->day_o;
	tmp = tmp | ((rtc_val->day_t&0x07)<<4);
	tmp = tmp | ((rtc_val->mon_o&0x0F)<<8);
	tmp = tmp | ((rtc_val->mon_t&0x07)<<12);
	__builtin_write_RTCWEN();
	RCFGCALbits.RTCWREN = 1;
	RCFGCALbits.RTCPTR = 2;
	RTCVAL = tmp;
	RCFGCALbits.RTCWREN = 0;
	}


uint8_t timer_elapsed (void)
	{
	if (IFS0bits.T1IF)
		{
		IFS0bits.T1IF = 0;
		return 1;
		}
	return 0;
	}


uint8_t keys_state (void)
	{
	uint8_t retval=0;
	if (KEY_1==0) retval = 0x01;
	if (KEY_2==0) retval = retval|0x02;
	if (KEY_3==0) retval = retval|0x04;
	if (KEY_4==0) retval = retval|0x08;
	return retval;
	}


uint8_t write_spi (uint8_t data)
	{
	uint8_t test;
	SPI1BUF = data;
	while(SPI1STATbits.SPIRBF==0);
	test = SPI1BUF;
	return test;
	}


void ee_wren (void)
	{
	MEM_CS = 0;
	write_spi(0x06);
	MEM_CS = 1;
	}

uint8_t ee_rdsr (void)
	{
	uint8_t tmp;
	MEM_CS = 0;
	write_spi(0x05);
	tmp = write_spi(0x00);
	MEM_CS = 1;
	return tmp;
	}
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
